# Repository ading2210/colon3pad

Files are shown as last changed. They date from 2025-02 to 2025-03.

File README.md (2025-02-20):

# colon3pad

This is a custom designed macro pad, created for the the [Hackpad](https://hackpad.hackclub.com/) event. It has 16 keys and a built in OLED display.

<p>
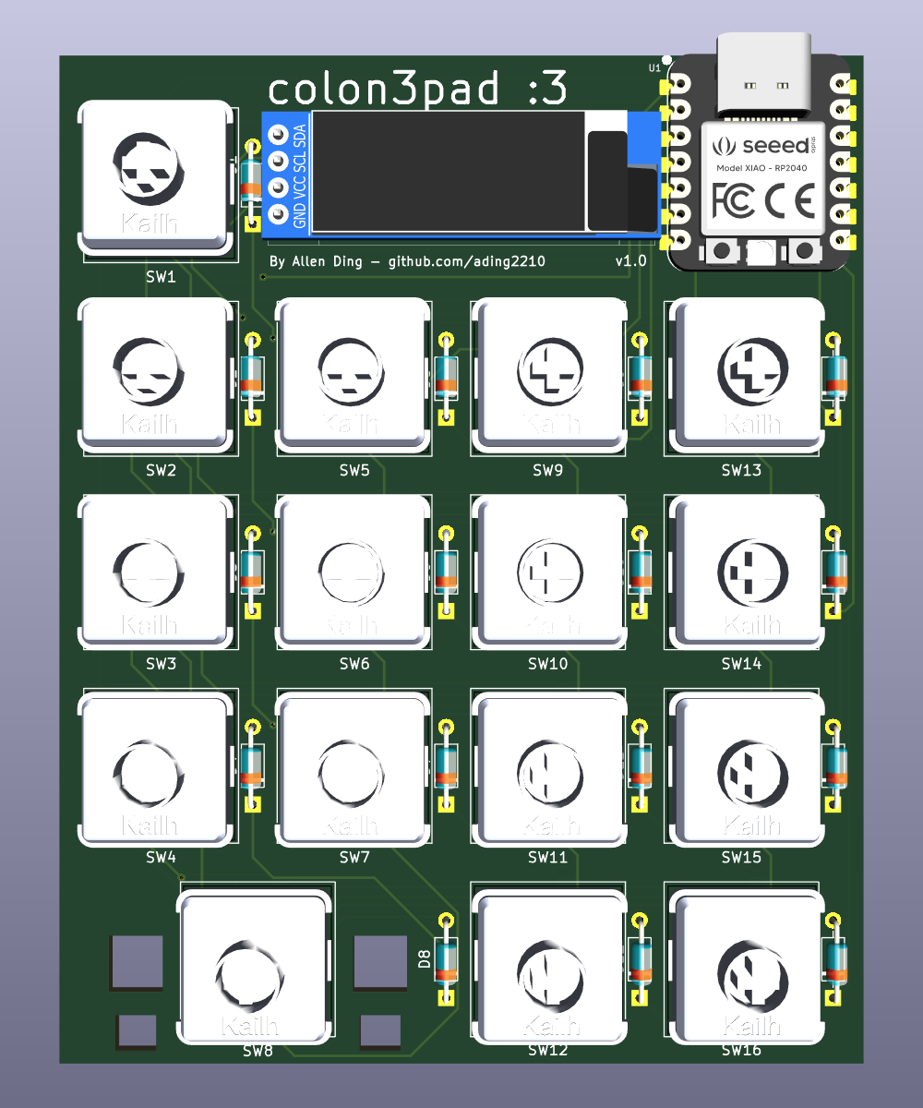
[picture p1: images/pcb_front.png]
   
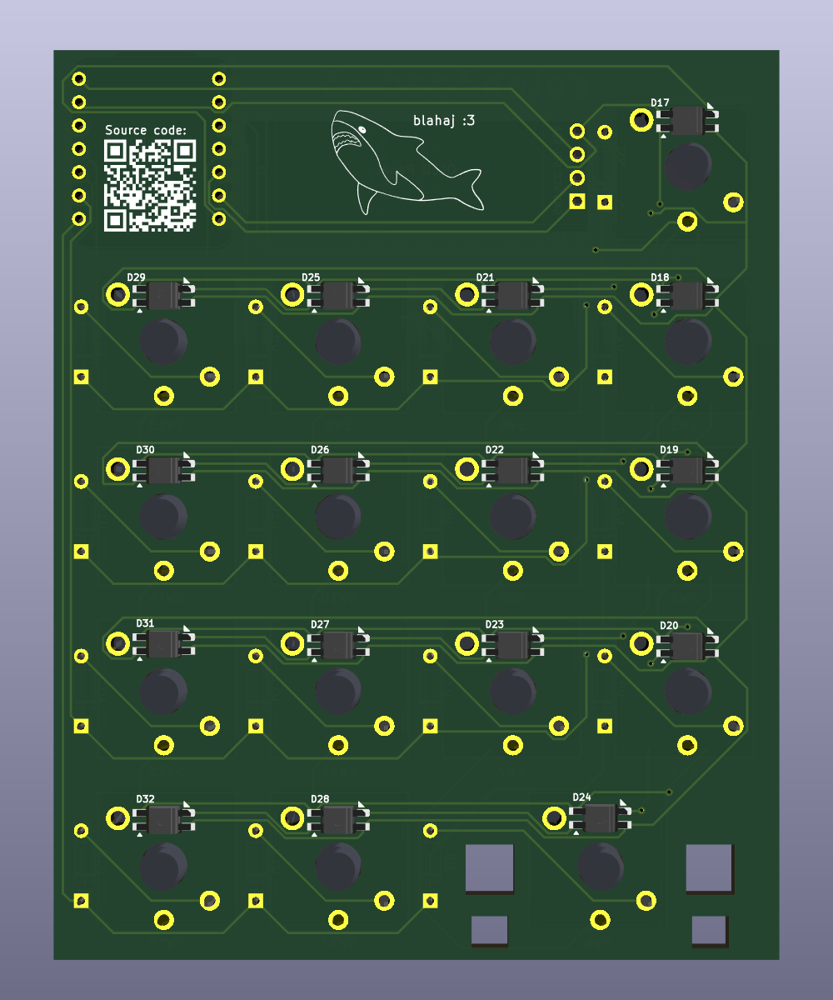
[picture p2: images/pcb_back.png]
   
</p>
<p>
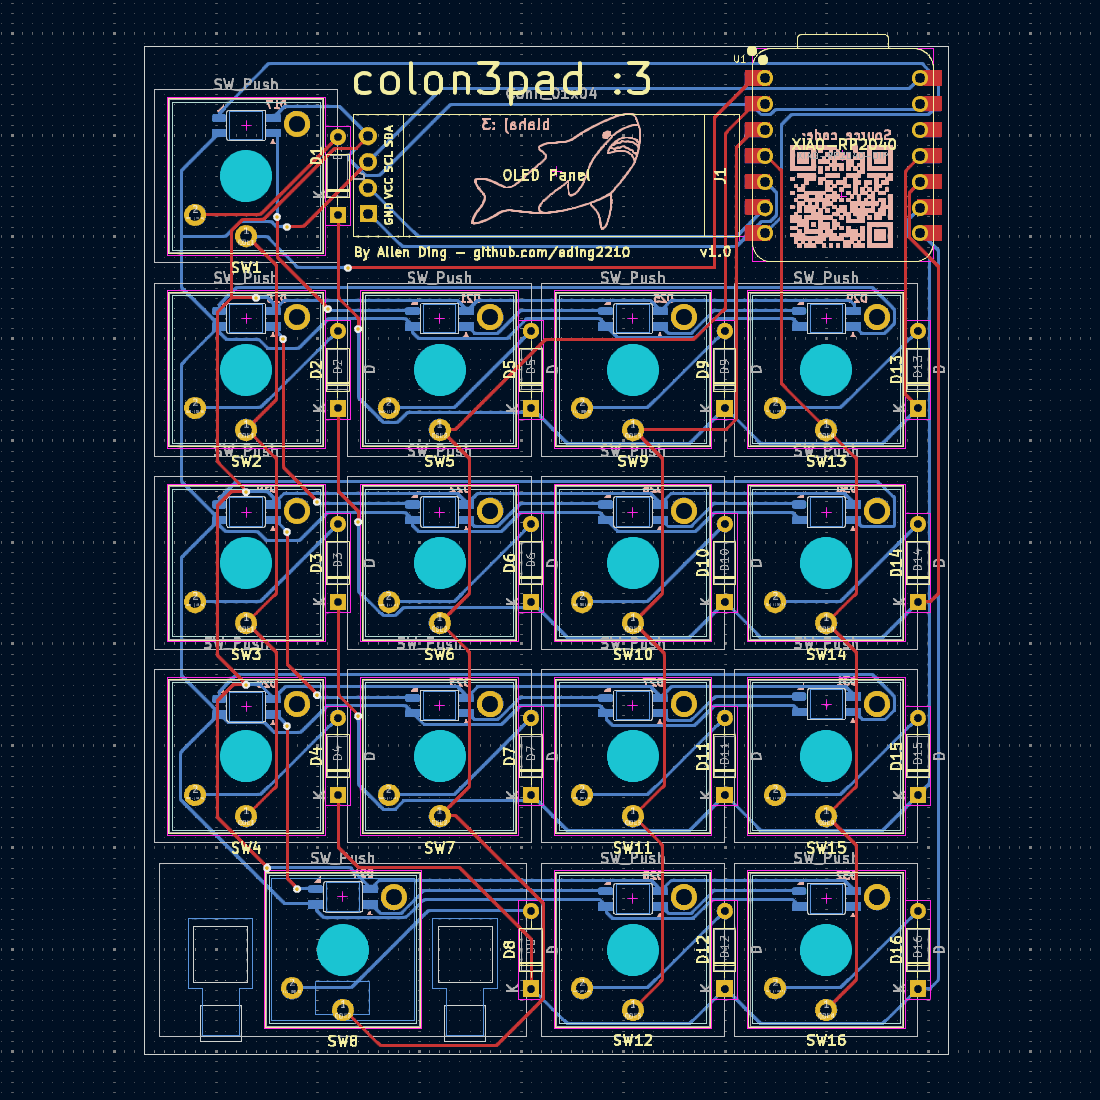
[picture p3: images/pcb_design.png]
   
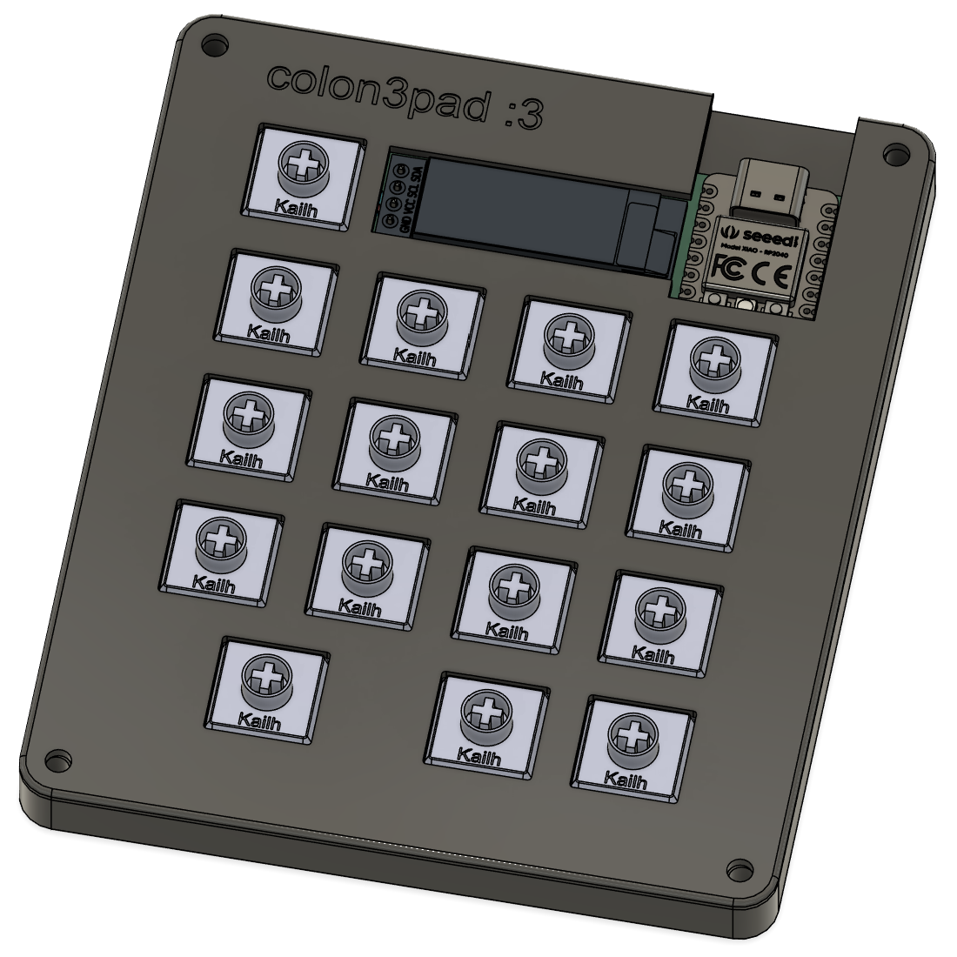
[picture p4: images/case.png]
   
</p>
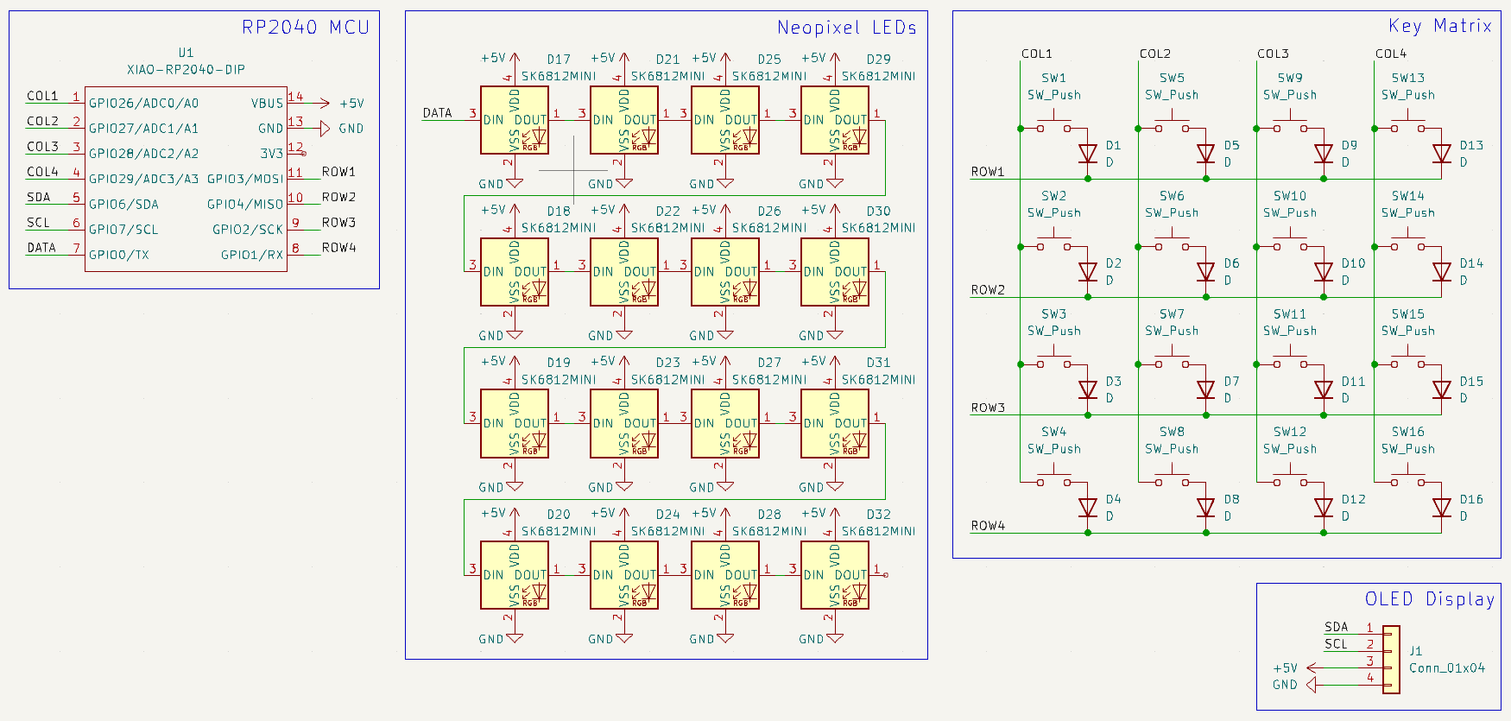
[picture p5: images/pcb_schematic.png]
 

## Inspiration / Challenges:

I designed this so I could get more practice with designing PCBs in KiCad. The fact that I'm [getting this hardware for free](https://hackpad.hackclub.com) also gave me an excuse to work on it. 

A challenge that I had was that I had to redo parts of the design several times. For example, I had finished the PCB when I realized that all the switches needed to be rotated 180°, so that forced me to reroute everything. Also, information on the PCB footprints and dimensions needed for the Choc V2 switches is somewhat scarce, so a ton of research was required. 

## BOM:
For PCB:
- 1x Seeed Studio XIAO RP2040 
- 1x SSD1306 128x32 OLED 
- 16x Kailh Choc V2 switches
- 16x SK6812-E reverse mount NeoPixel LEDs
- 16x 1N4148 diodes 

For Case:
- Case is 3D printed with PLA
- 4x M3x12mm screws
- 4x M3 hex nuts
- 4x M3x5mx4mm heatset inserts
- 15x 1u low profile key caps ([compatibility list](https://docs.google.com/spreadsheets/d/1ylYmEZ1jNiPuHWl6rjiI3xzooOwUTS33BZfYSW-n7Ok/edit?gid=0#gid=0))
- 1x 2u low profile key cap

## License:
This project is licensed under the GNU GPL v3. 
```
ading2210/colon3pad - A custom macro pad
Copyright (C) 2025 ading2210

This program is free software: you can redistribute it and/or modify
it under the terms of the GNU General Public License as published by
the Free Software Foundation, either version 3 of the License, or
(at your option) any later version.

This program is distributed in the hope that it will be useful,
but WITHOUT ANY WARRANTY; without even the implied warranty of
MERCHANTABILITY or FITNESS FOR A PARTICULAR PURPOSE.  See the
GNU General Public License for more details.

You should have received a copy of the GNU General Public License
along with this program.  If not, see <https://www.gnu.org/licenses/>.
```

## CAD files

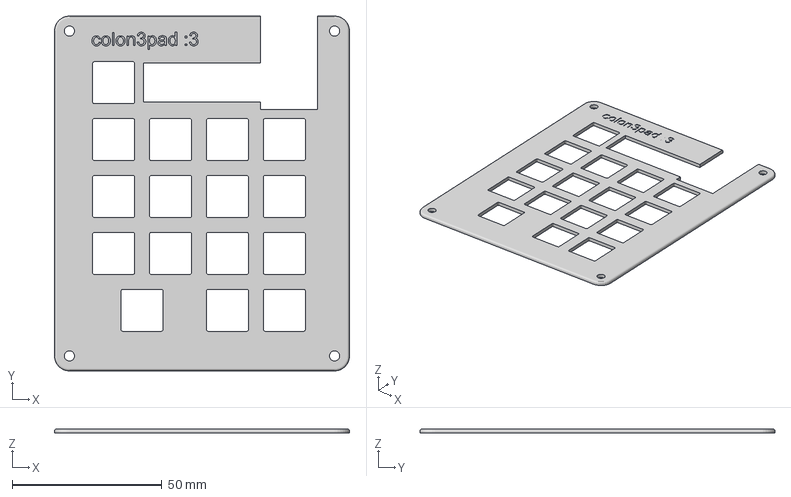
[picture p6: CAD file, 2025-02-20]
CAD/3mf/hackpad_case_plate.3mf
98.5 x 118.5 x 1.50 mm

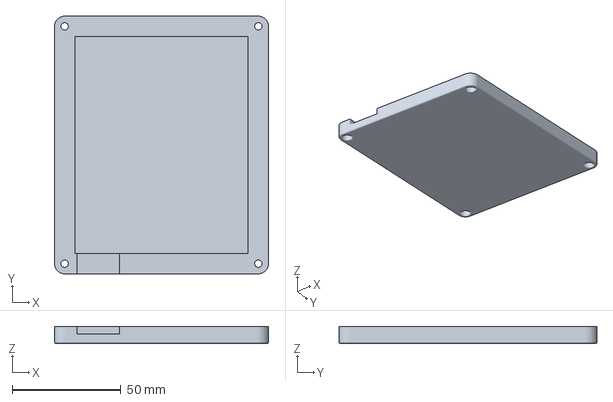
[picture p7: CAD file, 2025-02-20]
CAD/3mf/hackpad_case_base.3mf
98.5 x 118.5 x 8.00 mm

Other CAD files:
CAD/hackpad_case.f3z

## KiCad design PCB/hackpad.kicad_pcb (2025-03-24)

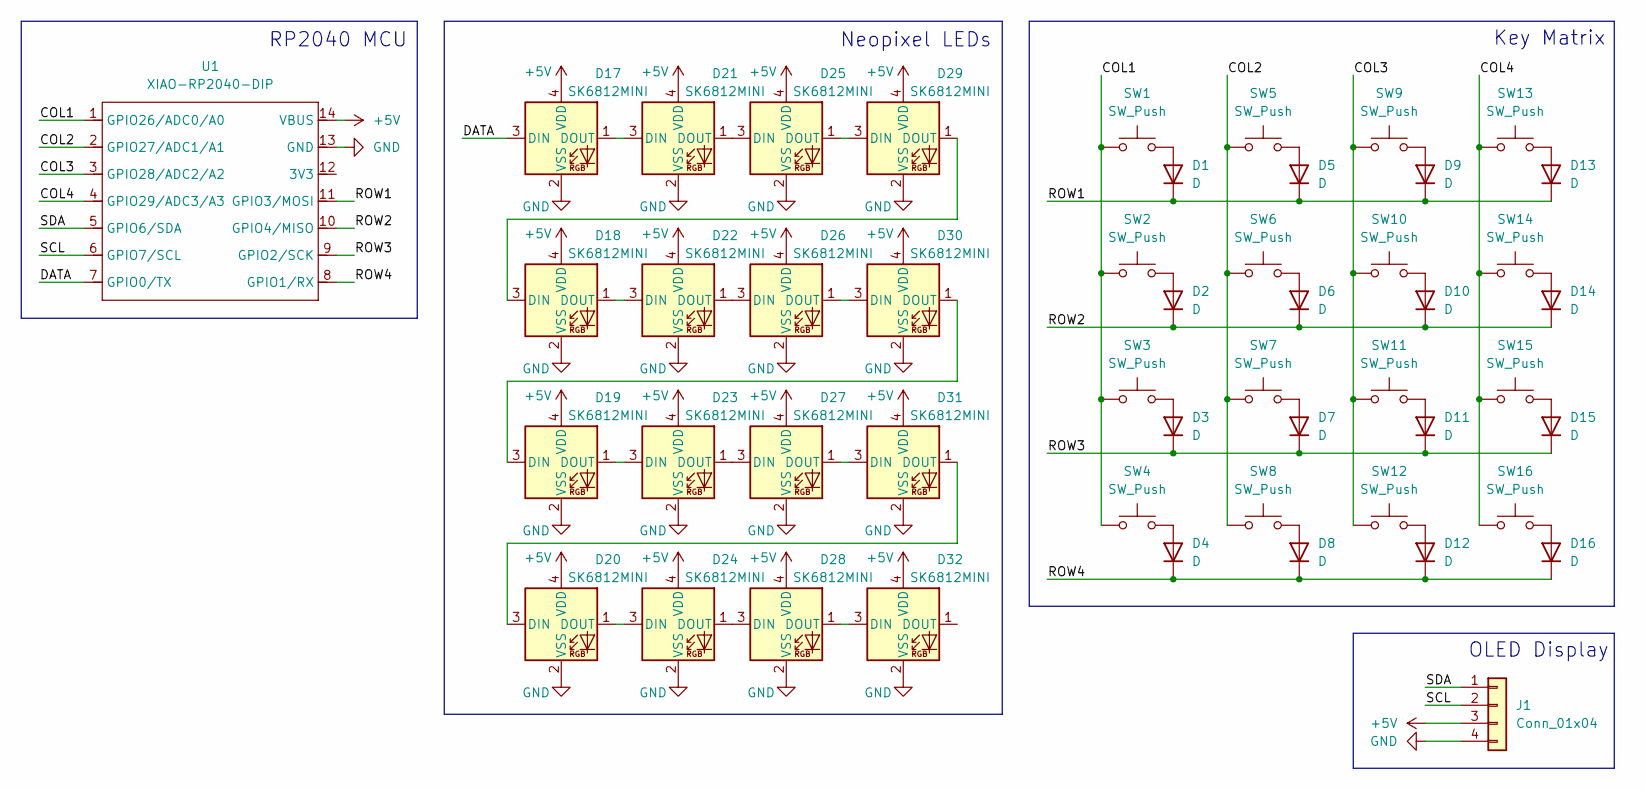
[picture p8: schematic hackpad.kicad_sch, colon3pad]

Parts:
D1, D2, D3, D4, D5, D6, D7, D8, D9, D10, D11, D12, D13, D14, D15, D16: D; D_DO-35_SOD27_P7.62mm_Horizontal
D17, D18, D19, D20, D21, D22, D23, D24, D25, D26, D27, D28, D29, D30, D31, D32: SK6812MINI; SK6812-MINI-E
J1: Conn_01x04; SSD1306-0.91-OLED-4pin-128x32
SW1, SW2, SW3, SW4, SW5, SW6, SW7, SW8, SW9, SW10, SW11, SW12, SW13, SW14, SW15, SW16: SW_Push; SW_Kailh_Choc_V2_1.00u
U1: XIAO-RP2040-DIP; MOUDLE14P-XIAO-DIP-SMD

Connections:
+5V: D17.4 (VDD), D18.4 (VDD), D19.4 (VDD), D20.4 (VDD), D21.4 (VDD), D22.4 (VDD), D23.4 (VDD), D24.4 (VDD), D25.4 (VDD), D26.4 (VDD), D27.4 (VDD), D28.4 (VDD), D29.4 (VDD), D30.4 (VDD), D31.4 (VDD), D32.4 (VDD), J1.3, U1.14 (VBUS)
/COL1: SW1.1, SW2.1, SW3.1, SW4.1, U1.1 (GPIO26/ADC0/A0)
/COL2: SW5.1, SW6.1, SW7.1, SW8.1, U1.2 (GPIO27/ADC1/A1)
/COL3: SW9.1, SW10.1, SW11.1, SW12.1, U1.3 (GPIO28/ADC2/A2)
/COL4: SW13.1, SW14.1, SW15.1, SW16.1, U1.4 (GPIO29/ADC3/A3)
/DATA: D17.3 (DIN), U1.7 (GPIO0/TX)
/ROW1: D1.1 (K), D5.1 (K), D9.1 (K), D13.1 (K), U1.11 (GPIO3/MOSI)
/ROW2: D2.1 (K), D6.1 (K), D10.1 (K), D14.1 (K), U1.10 (GPIO4/MISO)
/ROW3: D3.1 (K), D7.1 (K), D11.1 (K), D15.1 (K), U1.9 (GPIO2/SCK)
/ROW4: D4.1 (K), D8.1 (K), D12.1 (K), D16.1 (K), U1.8 (GPIO1/RX)
/SCL: J1.2, U1.6 (GPIO7/SCL)
/SDA: J1.1, U1.5 (GPIO6/SDA)
GND: D17.2 (VSS), D18.2 (VSS), D19.2 (VSS), D20.2 (VSS), D21.2 (VSS), D22.2 (VSS), D23.2 (VSS), D24.2 (VSS), D25.2 (VSS), D26.2 (VSS), D27.2 (VSS), D28.2 (VSS), D29.2 (VSS), D30.2 (VSS), D31.2 (VSS), D32.2 (VSS), J1.4, U1.13 (GND)
unnamed: D1.2 (A), SW1.2
unnamed: D2.2 (A), SW2.2
unnamed: D3.2 (A), SW3.2
unnamed: D4.2 (A), SW4.2
unnamed: D5.2 (A), SW5.2
unnamed: D6.2 (A), SW6.2
unnamed: D7.2 (A), SW7.2
unnamed: D8.2 (A), SW8.2
unnamed: D9.2 (A), SW9.2
unnamed: D10.2 (A), SW10.2
unnamed: D11.2 (A), SW11.2
unnamed: D12.2 (A), SW12.2
unnamed: D13.2 (A), SW13.2
unnamed: D14.2 (A), SW14.2
unnamed: D15.2 (A), SW15.2
unnamed: D16.2 (A), SW16.2
unnamed: D17.1 (DOUT), D21.3 (DIN)
unnamed: D18.3 (DIN), D29.1 (DOUT)
unnamed: D18.1 (DOUT), D22.3 (DIN)
unnamed: D19.3 (DIN), D30.1 (DOUT)
unnamed: D19.1 (DOUT), D23.3 (DIN)
unnamed: D20.3 (DIN), D31.1 (DOUT)
unnamed: D20.1 (DOUT), D24.3 (DIN)
unnamed: D21.1 (DOUT), D25.3 (DIN)
unnamed: D22.1 (DOUT), D26.3 (DIN)
unnamed: D23.1 (DOUT), D27.3 (DIN)
unnamed: D24.1 (DOUT), D28.3 (DIN)
unnamed: D25.1 (DOUT), D29.3 (DIN)
unnamed: D26.1 (DOUT), D30.3 (DIN)
unnamed: D27.1 (DOUT), D31.3 (DIN)
unnamed: D28.1 (DOUT), D32.3 (DIN)

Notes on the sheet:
OLED Display
Neopixel LEDs
Key Matrix
RP2040 MCU

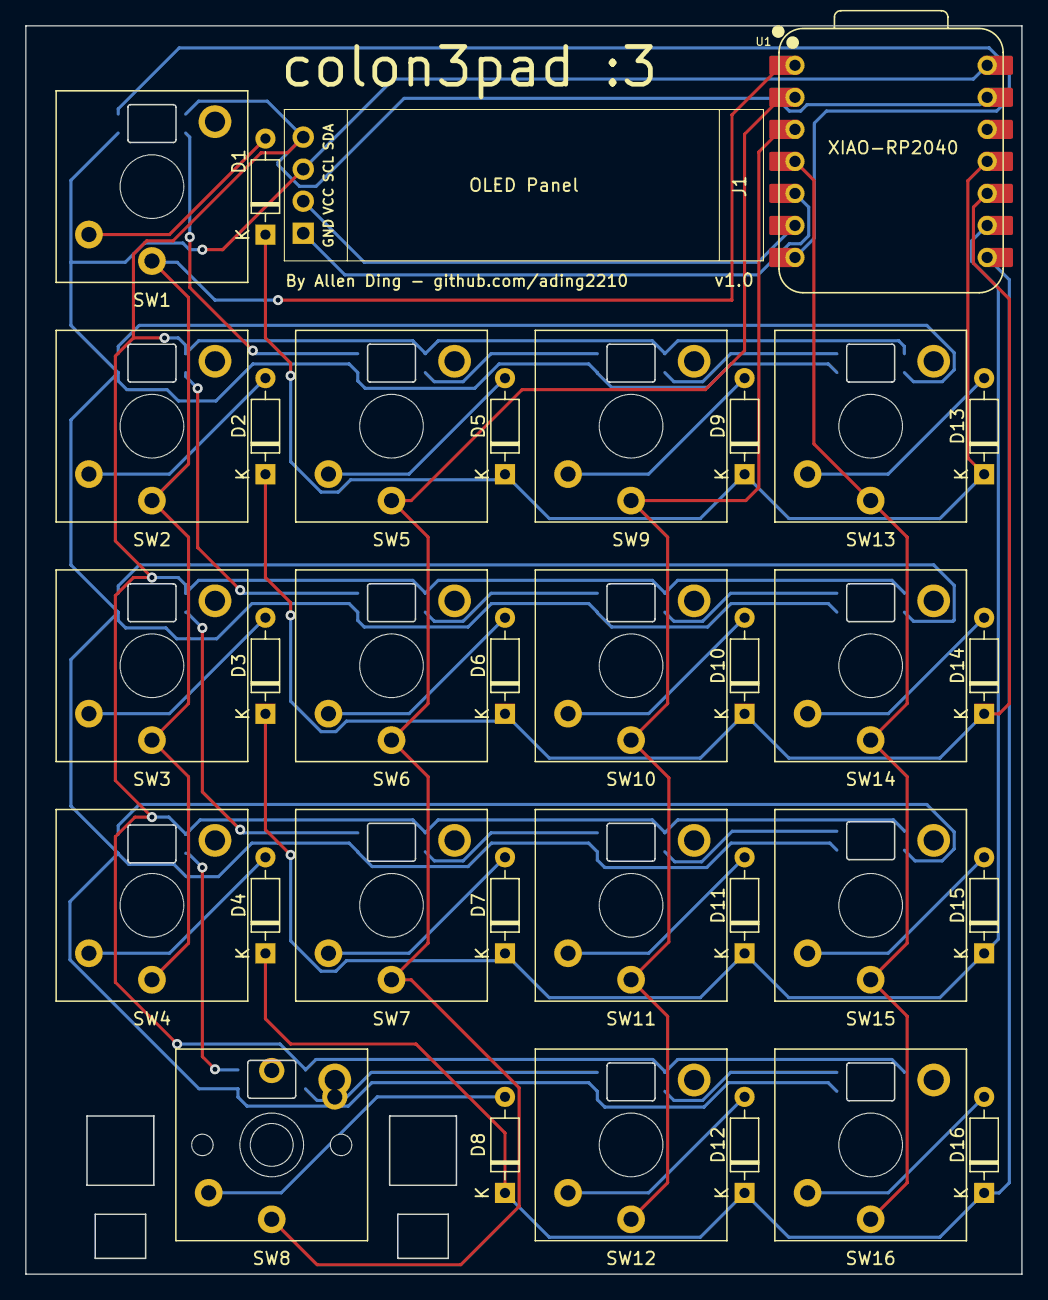
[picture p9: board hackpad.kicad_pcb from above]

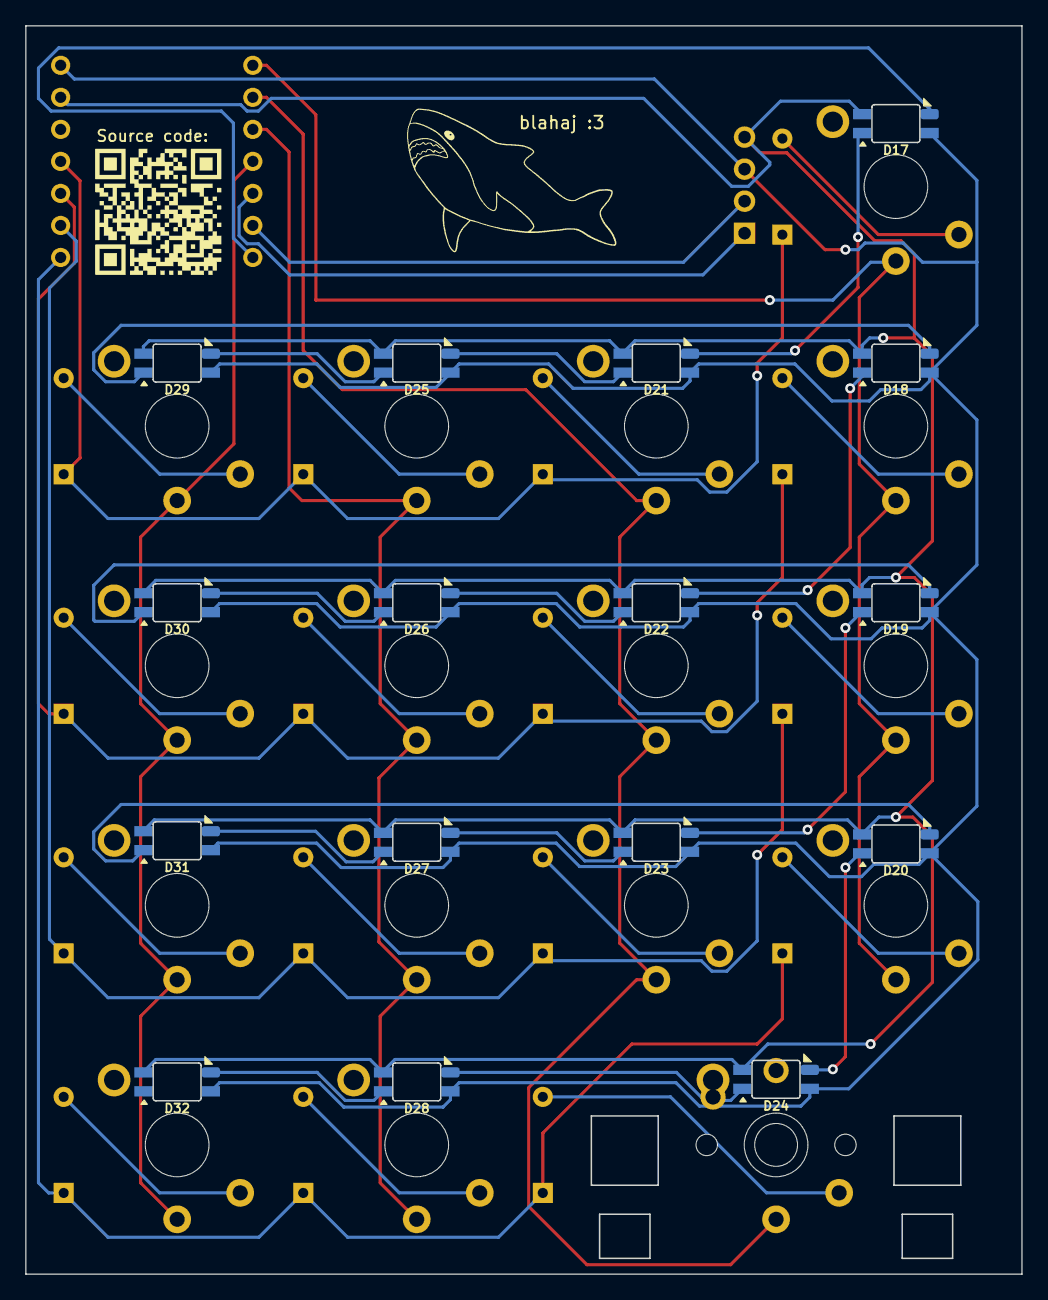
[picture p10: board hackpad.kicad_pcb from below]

Board: 2 copper layers, 79.0 x 99.0 mm, 51 parts (16 on the bottom side), 44 nets.

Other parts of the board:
2u: Choc-2u-solder

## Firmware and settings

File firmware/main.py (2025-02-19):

import board

from kmk.kmk_keyboard import KMKKeyboard
from kmk.scanners.keypad import MatrixScanner
from kmk.keys import KC
from kmk.extensions.RGB import RGB
from kmk.modules.macros import Press, Release, Tap, Macros

keyboard = KMKKeyboard()
macros = Macros()
keyboard.modules.append(macros)

COL_PINS = [board.GP26, board.GP27, board.GP28, board.GP29]
ROW_PINS = [board.GP3, board.GP4, board.GP2, board.GP1]

keyboard.matrix = MatrixScanner(
  column_pins = COL_PINS,
  row_pins = ROW_PINS
)

ALT_F4_MACRO = KC.MACRO(
  Press(KC.LALT),
  Tap(KC.F4),
  Release(KC.LALT)
)

keyboard.keymap = [
  [KC.NUMLOCK, KC.KP_8, KC.KP_9,   KC.BSPACE],
  [KC.KP_7,    KC.KP_5, KC.KP_6,   ALT_F4_MACRO],
  [KC.KP_4,    KC.KP_2, KC.KP_3,   KC.PSCREEN],
  [KC.KP_1,    KC.KP_0, KC.KP_DOT, KC.KP_ENTER],
]

rgb = RGB(pixel_pin=board.GP0, num_pixels=16)
rgb.set_rgb_fill(255, 255, 255)
keyboard.extensions.append(rgb)

if __name__ == "__main__":
    keyboard.go()

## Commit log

2025-02-17 add keys, oled, neopixels to schematic
    [hackpad.kicad_sch]
2025-02-17 add footprint submodules, first version of the pcb
    [hackpad.kicad_pcb, hackpad.kicad_sch]
2025-02-17 add branding to pcb
    [hackpad.kicad_pcb]
2025-02-17 add 3d models to pcb
    [Kailh-Choc-V2.step, OLED_0.91_128x32.step, OLED_0.91_128x32_trimmed.step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]
2025-02-17 rotate all key switches and redo routing
    [hackpad.kicad_pcb]
2025-02-17 move all pcb stuff into subdirectory
    [Kailh-Choc-V2.step, OLED_0.91_128x32.step, OLED_0.91_128x32_trimmed.step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]
2025-02-17 add fusion360 cad files
    [hackpad_case.f3z]
2025-02-18 finalize pcb traces and silkscreen text
    [hackpad.kicad_pcb, hackpad.kicad_sch]
2025-02-19 add cutouts for key stabilizer
    [hackpad.kicad_pcb]
2025-02-19 add license, readme, and bom
    [hackpad.kicad_pcb]
2025-02-20 update pcb with new footprint for stabilizer
    [hackpad.kicad_pcb]
2025-02-20 update case cad files
    [hackpad_case.f3z, hackpad_case_base.3mf, hackpad_case_plate.3mf]
2025-02-21 export gerber files
    [hackpad.kicad_pcb]
2025-03-24 add initial kicad files for hackboard
    [hackboard.kicad_pcb, hackboard.kicad_sch]
2025-03-24 move kicad libraries to third_party dir, update to kicad 9.0
    [hackpad.kicad_pcb, hackpad.kicad_sch]
2025-03-24 Revert "add initial kicad files for hackboard"
    This reverts commit 026ab9f43395aebb26b94a7c593d4d996977a634.
    [hackboard.kicad_pcb, hackboard.kicad_sch]
